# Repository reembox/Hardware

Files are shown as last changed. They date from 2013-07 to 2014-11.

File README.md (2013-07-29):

Hardware
========

This repository contains pcb layout files for the reembox project.

The layout files can be opened with [EAGLE](http://www.cadsoft.de/download-eagle/) version 6.4.0 or higher. Since the board fits on a half eurocard, you can use EAGLE in the freeware version without buying a licence.

Check out the [Wiki documentation](https://github.com/reembox/Hardware/wiki) for setting it up.

This project "reembox" © 2013 Jonas Eickhoff is licensed under the Creative Commons Attribution-ShareAlike 3.0 Unported License: http://creativecommons.org/licenses/by-sa/3.0/

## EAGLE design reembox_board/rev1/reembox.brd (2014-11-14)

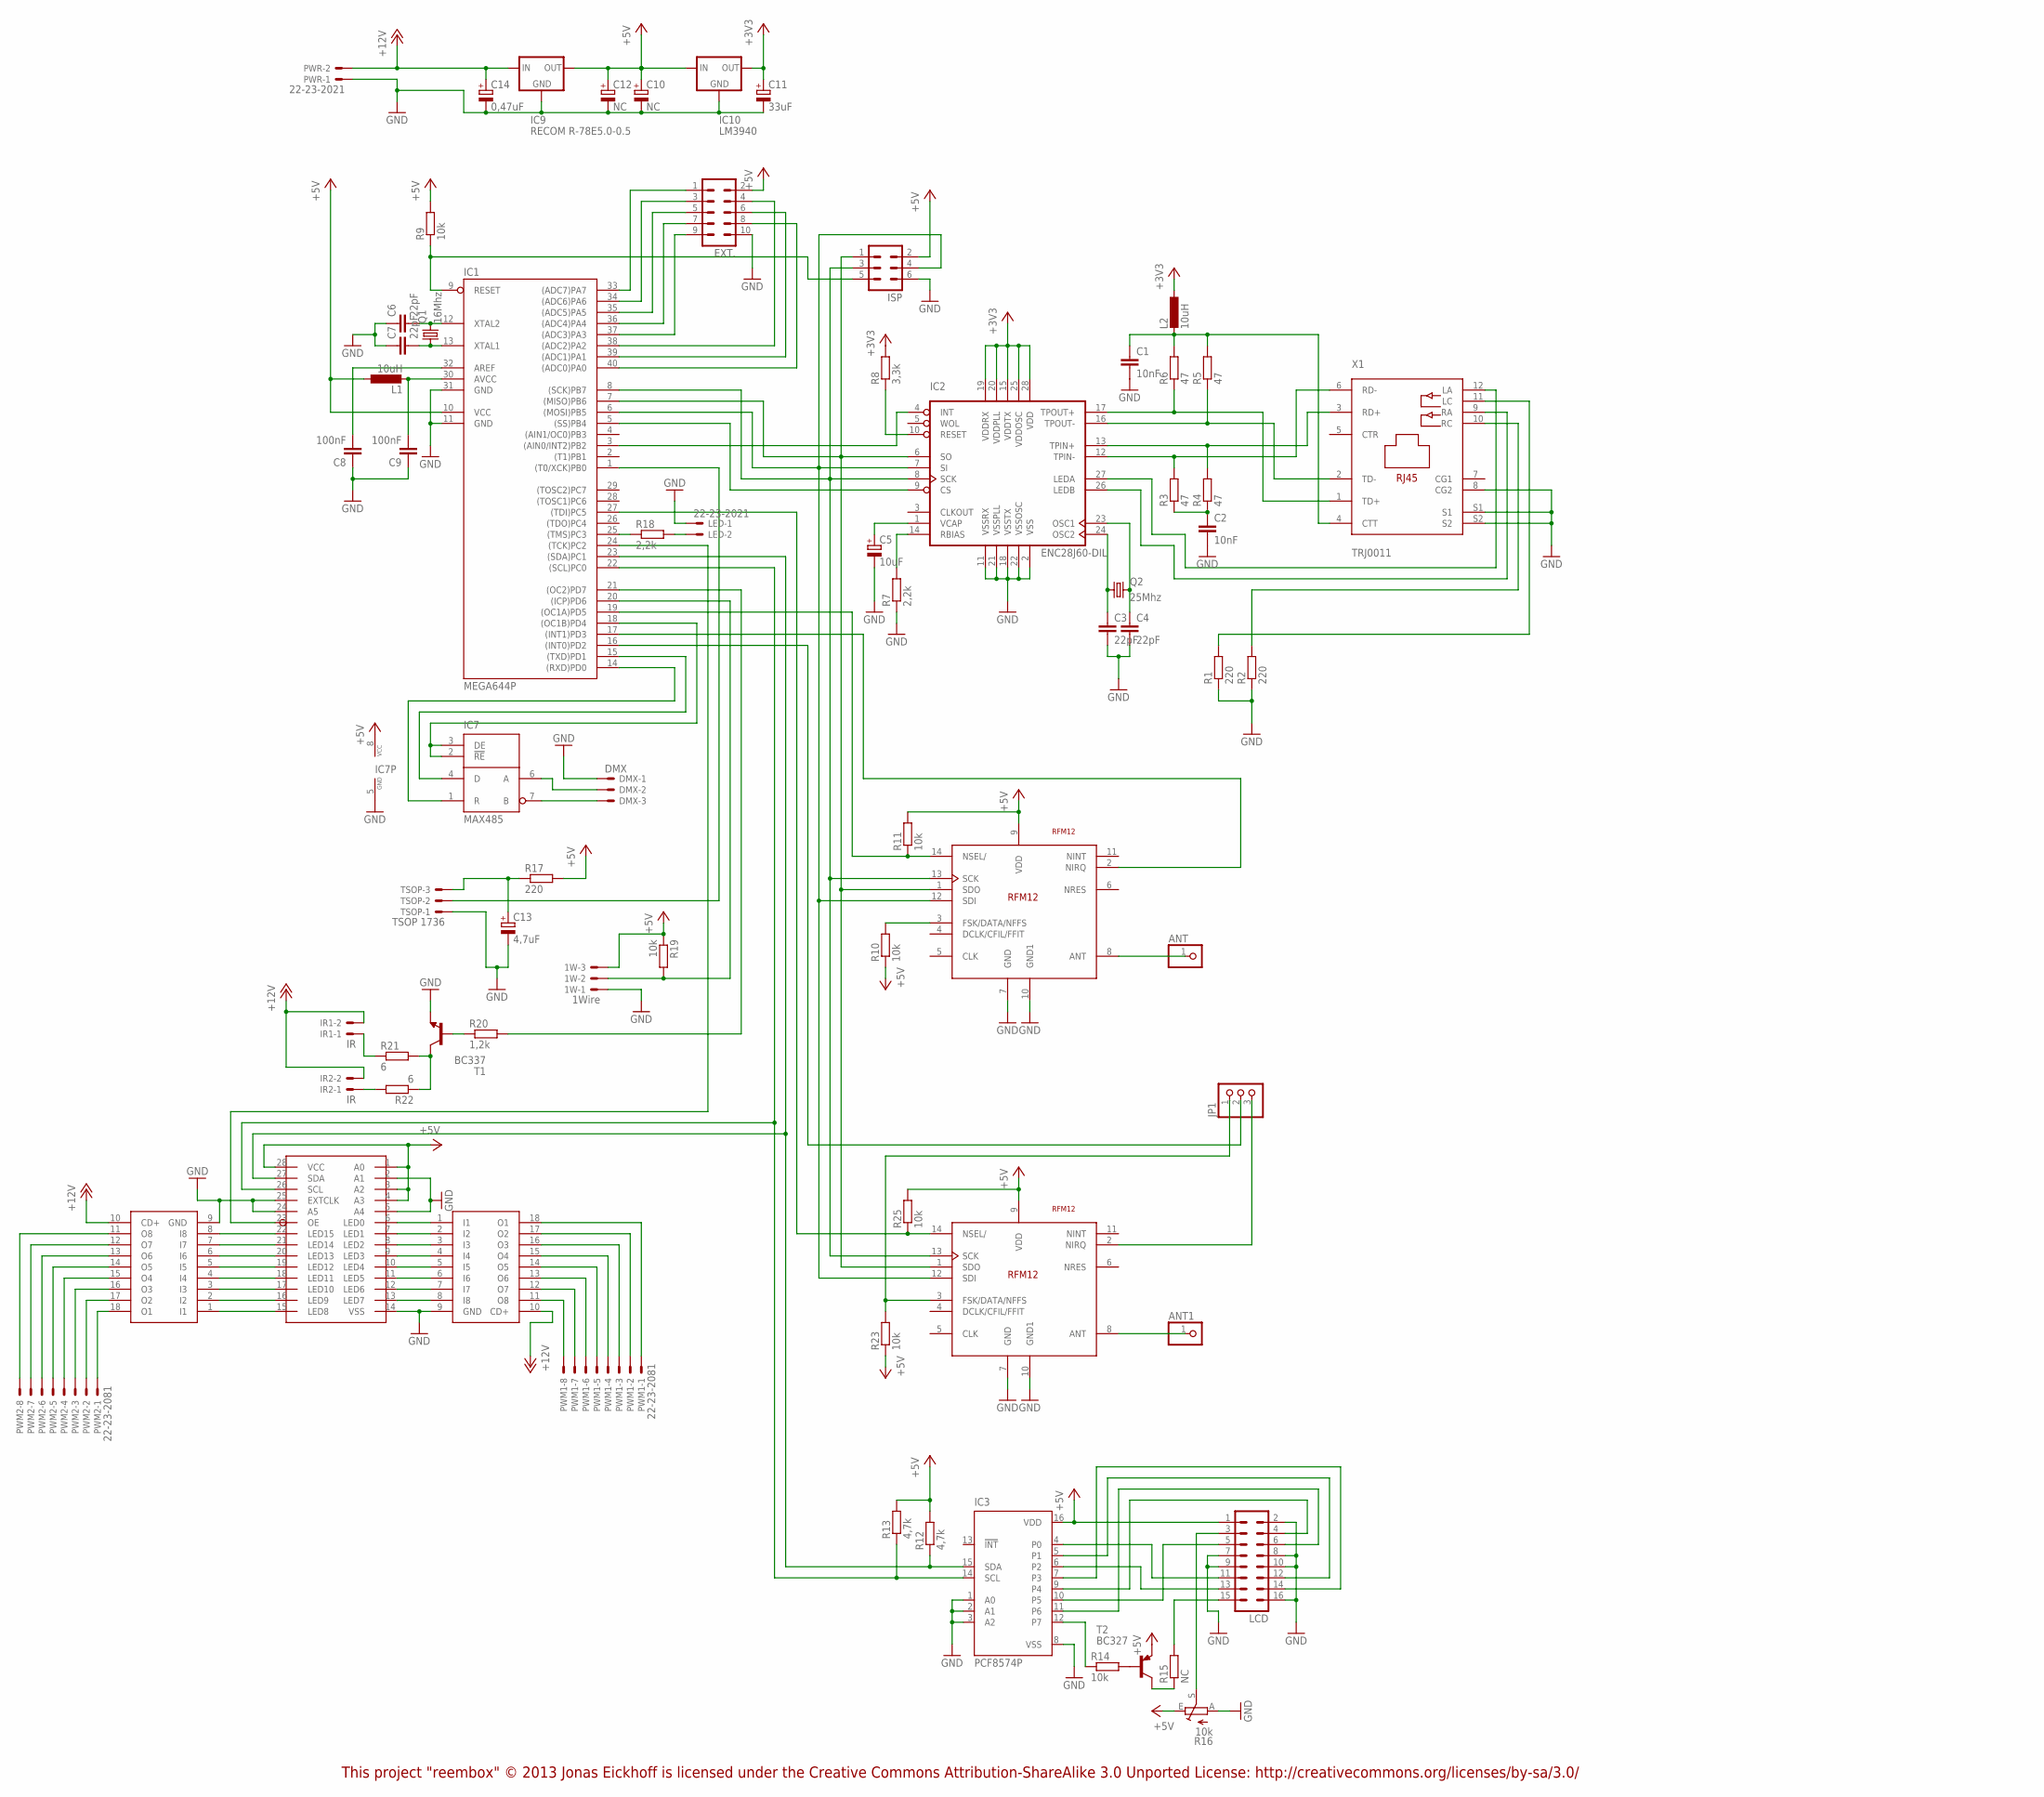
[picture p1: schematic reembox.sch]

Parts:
1W: 1Wire; CON-MOLEX_22-23-2031
ANT, ANT1: PINHD-1X1; 1X01
C1, C2: 10nF; C050-025X075
C3, C4, C6, C7: 22pF; C050-024X044
C5: 10uF; E2,5-6
C8, C9: 100nF; C050-025X075
C10, C12: NC; E2,5-6
C11: 33uF; E2,5-6
C13: 4,7uF; E2,5-6E
C14: 0,47uF; E2,5-6
DMX: DMX; 22-23-2031
EXT.: ML10L
IC1: MEGA644P; DIL40
IC2: ENC28J60-DIL; DIL28-3
IC3: PCF8574P; DIL16
IC4: PCA9685PW; TSSOP28
IC5, IC6: ULN2803; DIL18
IC7: MAX485; DIL08
IC8, IC11: RFM12
IC9: RECOM R-78E5.0-0.5; 78XXS
IC10: LM3940; 78XXS
IR1: IR; 22-23-2021
IR2: IR; 22-23-2021; MPN 22-23-2021
ISP: ML6
JP1: PINHD-1X3; 1X03
L1, L2: 10uH; 0207/2V
LCD: ML16
LED: 22-23-2021; MPN 22-23-2021
PWM1, PWM2: 22-23-2081
PWR: 22-23-2021
Q1: 16Mhz; HC49U-V
Q2: 25Mhz; HC49U-V
R1, R2, R17: 220; 0207/2V
R3, R4, R5, R6: 47; 0207/2V
R7: 2,2k; 0207/7
R8: 3,3k; 0207/10
R9, R25: 10k; 0207/2V
R10, R11, R14, R19, R23: 10k; 0207/10
R12, R13: 4,7k; 0207/10
R15: NC; 0207/10
R16: 10k; PT-10S
R18: 2,2k; 0207/2V
R20: 1,2k; RCL_0207/2V
R21, R22: 6; RCL_0207/2V
T1: BC337; TO92
T2: BC327; TO92
TSOP: TSOP 1736; 22-23-2031
X1: TRJ0011

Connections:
+3V3: C11.+, IC2.15 (VDDTX), IC2.19 (VDDRX), IC2.20 (VDDPLL), IC2.25 (VDDOSC), IC2.28 (VDD), IC10.OUT, L2.1, R8.2
+5V: 1W.3, C10.+, C12.+, EXT..2, IC1.10 (VCC), IC3.16 (VDD), IC4.1 (A0), IC4.3 (A2), IC4.4 (A3), IC4.28 (VCC), IC7.8 (VCC), IC8.9 (VDD), IC9.OUT, IC10.IN, IC11.9 (VDD), ISP.2, L1.1, LCD.1, R9.2, R10.1, R11.2, R12.2, R13.2, R16.E, R17.2, R19.1, R23.1, R25.2, T2.1 (E)
+12V: C14.+, IC5.10 (CD+), IC6.10 (CD+), IC9.IN, IR1.2, IR2.2, PWR.2
GND: 1W.1, C1.2, C2.2, C3.2, C4.2, C5.-, C6.1, C7.1, C8.1, C9.1, C10.-, C11.-, C12.-, C13.-, C14.-, DMX.1, EXT..10, IC1.11 (GND), IC1.31 (GND), IC2.2 (VSS), IC2.11 (VSSRX), IC2.18 (VSSTX), IC2.21 (VSSPLL), IC2.22 (VSSOSC), IC3.1 (A0), IC3.2 (A1), IC3.3 (A2), IC3.8 (VSS), IC4.2 (A1), IC4.5 (A4), IC4.14 (VSS), IC4.24 (A5), IC4.25 (EXTCLK), IC5.9 (GND), IC6.9 (GND), IC7.5 (GND), IC8.7 (GND), IC8.10 (GND1), IC9.GND, IC10.GND, IC11.7 (GND), IC11.10 (GND1), ISP.6, LCD.2, LCD.7, LCD.8, LCD.9, LCD.10, LCD.16, LED.1, PWR.1, R1.1, R2.1, R7.1, R16.A, T1.1 (E), TSOP.1, X1.8 (CG2), X1.S1, X1.S2
LED: IC1.1 ((T0/XCK)PB0), TSOP.2
unnamed: IC2.17 (TPOUT+), R6.1, X1.1 (TD+)
unnamed: IC2.16 (TPOUT-), R5.1, X1.2 (TD-)
unnamed: IC2.13 (TPIN+), R4.2, X1.3 (RD+)
unnamed: IC2.12 (TPIN-), R3.2, X1.6 (RD-)
unnamed: IC2.27 (LEDA), X1.12 (LA)
unnamed: IC2.26 (LEDB), X1.9 (RA)
unnamed: R2.2, X1.10 (RC)
unnamed: R1.2, X1.11 (LC)
unnamed: C2.1, R3.1, R4.1
unnamed: C3.1, IC2.24 (OSC2), Q2.1
unnamed: C4.1, IC2.23 (OSC1), Q2.2
unnamed: C1.1, L2.2, R5.2, R6.2, X1.4 (CTT)
unnamed: IC2.10 (RESET), R8.1
unnamed: IC2.14 (RBIAS), R7.2
unnamed: C5.+, IC2.1 (VCAP)
unnamed: C6.2, IC1.12 (XTAL2), Q1.2
unnamed: C7.2, IC1.13 (XTAL1), Q1.1
unnamed: IC1.5 ((SS)PB4), IC2.9 (CS)
unnamed: IC1.17 ((INT1)PD3), IC8.2 (NIRQ)
unnamed: IC1.27 ((TDI)PC5), IC11.14 (NSEL/), R25.1
unnamed: IC1.16 ((INT0)PD2), JP1.2
unnamed: C8.2, IC1.32 (AREF)
unnamed: IC1.3 ((AIN0/INT2)PB2), IC2.4 (INT)
unnamed: IC1.9 (RESET), ISP.5, R9.1
unnamed: IC1.19 ((OC1A)PD5), IC8.14 (NSEL/), R11.1
unnamed: C9.2, IC1.30 (AVCC), L1.2
unnamed: DMX.2, IC7.6 (A)
unnamed: IC1.18 ((OC1B)PD4), IC7.2 (!RE), IC7.3 (DE)
unnamed: DMX.3, IC7.7 (B)
unnamed: IC1.15 ((TXD)PD1), IC7.4 (D)
unnamed: IC1.14 ((RXD)PD0), IC7.1 (R)
unnamed: IC1.23 ((SDA)PC1), IC3.15 (SDA), IC4.27 (SDA), R12.1
unnamed: IC1.22 ((SCL)PC0), IC3.14 (SCL), IC4.26 (SCL), R13.1
unnamed: IC3.12 (P7), R14.1
unnamed: R14.2, T2.2 (B)
unnamed: R15.1, T2.3 (C)
unnamed: LCD.15, R15.2
unnamed: IC3.4 (P0), LCD.11
unnamed: IC3.5 (P1), LCD.12
unnamed: IC3.6 (P2), LCD.13
unnamed: IC3.7 (P3), LCD.14
unnamed: IC3.9 (P4), LCD.4
unnamed: IC3.10 (P5), LCD.5
unnamed: IC3.11 (P6), LCD.6
unnamed: ANT.1, IC8.8 (ANT)
unnamed: IC1.24 ((TCK)PC2), IC4.23 (OE)
unnamed: LCD.3, R16.S
unnamed: C13.+, R17.1, TSOP.3
unnamed: IC4.15 (LED8), IC5.1 (I1)
unnamed: IC1.21 ((OC2)PD7), R20.2
unnamed: IC1.8 ((SCK)PB7), IC2.8 (SCK), IC8.13 (SCK), IC11.13 (SCK), ISP.3
unnamed: 1W.2, IC1.20 ((ICP)PD6), R19.2
unnamed: R20.1, T1.2 (B)
unnamed: IC4.16 (LED9), IC5.2 (I2)
unnamed: R21.2, R22.1, T1.3 (C)
unnamed: IR1.1, R21.1
unnamed: IC4.17 (LED10), IC5.3 (I3)
unnamed: IC4.18 (LED11), IC5.4 (I4)
unnamed: IC4.19 (LED12), IC5.5 (I5)
unnamed: IC4.20 (LED13), IC5.6 (I6)
unnamed: IC4.21 (LED14), IC5.7 (I7)
unnamed: IC4.22 (LED15), IC5.8 (I8)
unnamed: IC4.6 (LED0), IC6.1 (I1)
unnamed: IC4.8 (LED2), IC6.3 (I3)
unnamed: IC4.7 (LED1), IC6.2 (I2)
unnamed: IC4.10 (LED4), IC6.5 (I5)
unnamed: IC4.9 (LED3), IC6.4 (I4)
unnamed: IC4.12 (LED6), IC6.7 (I7)
unnamed: IC4.11 (LED5), IC6.6 (I6)
unnamed: IC4.13 (LED7), IC6.8 (I8)
unnamed: IC6.13 (O6), PWM1.6
unnamed: IC6.17 (O2), PWM1.2
unnamed: IC5.18 (O1), PWM2.1
unnamed: IC5.17 (O2), PWM2.2
unnamed: IC5.16 (O3), PWM2.3
unnamed: IC5.15 (O4), PWM2.4
unnamed: IC5.14 (O5), PWM2.5
unnamed: IC5.13 (O6), PWM2.6
unnamed: IC5.12 (O7), PWM2.7
unnamed: IC5.11 (O8), PWM2.8
unnamed: IC6.11 (O8), PWM1.8
unnamed: IC6.12 (O7), PWM1.7
unnamed: IC6.14 (O5), PWM1.5
unnamed: IC6.15 (O4), PWM1.4
unnamed: IC6.16 (O3), PWM1.3
unnamed: IC6.18 (O1), PWM1.1
unnamed: IC1.25 ((TMS)PC3), R18.1
unnamed: EXT..1, IC1.33 ((ADC7)PA7)
unnamed: EXT..3, IC1.34 ((ADC6)PA6)
unnamed: EXT..5, IC1.35 ((ADC5)PA5)
unnamed: EXT..7, IC1.36 ((ADC4)PA4)
unnamed: EXT..9, IC1.37 ((ADC3)PA3)
unnamed: EXT..4, IC1.38 ((ADC2)PA2)
unnamed: EXT..6, IC1.39 ((ADC1)PA1)
unnamed: EXT..8, IC1.40 ((ADC0)PA0)
unnamed: IC1.6 ((MOSI)PB5), IC2.7 (SI), IC8.12 (SDI), IC11.12 (SDI), ISP.4
unnamed: LED.2, R18.2
unnamed: IR2.1, R22.2
unnamed: IC1.7 ((MISO)PB6), IC2.6 (SO), IC8.1 (SDO), IC11.1 (SDO), ISP.1
unnamed: IC11.3 (FSK/DATA/NFFS), JP1.1, R23.2
unnamed: IC11.2 (NIRQ), JP1.3
unnamed: ANT1.1, IC11.8 (ANT)
unnamed: IC8.3 (FSK/DATA/NFFS), R10.2

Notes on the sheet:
This project "reembox" © 2013 Jonas Eickhoff is licensed under the Creative Commons Attribution-ShareAlike 3.0 Unported License: http://creativecommons.org/licenses/by-sa/3.0/

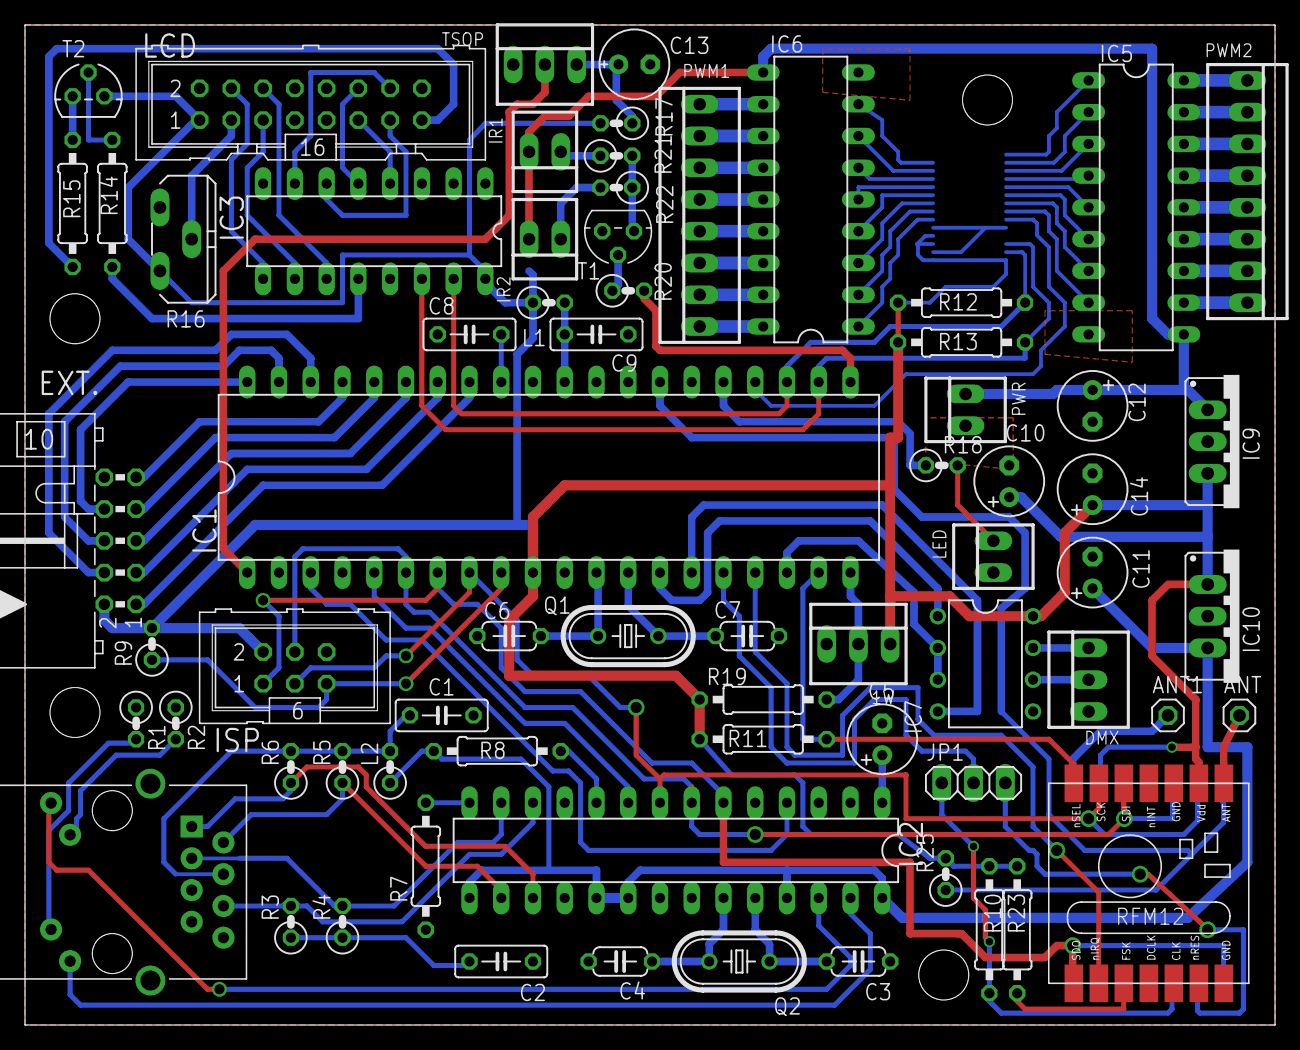
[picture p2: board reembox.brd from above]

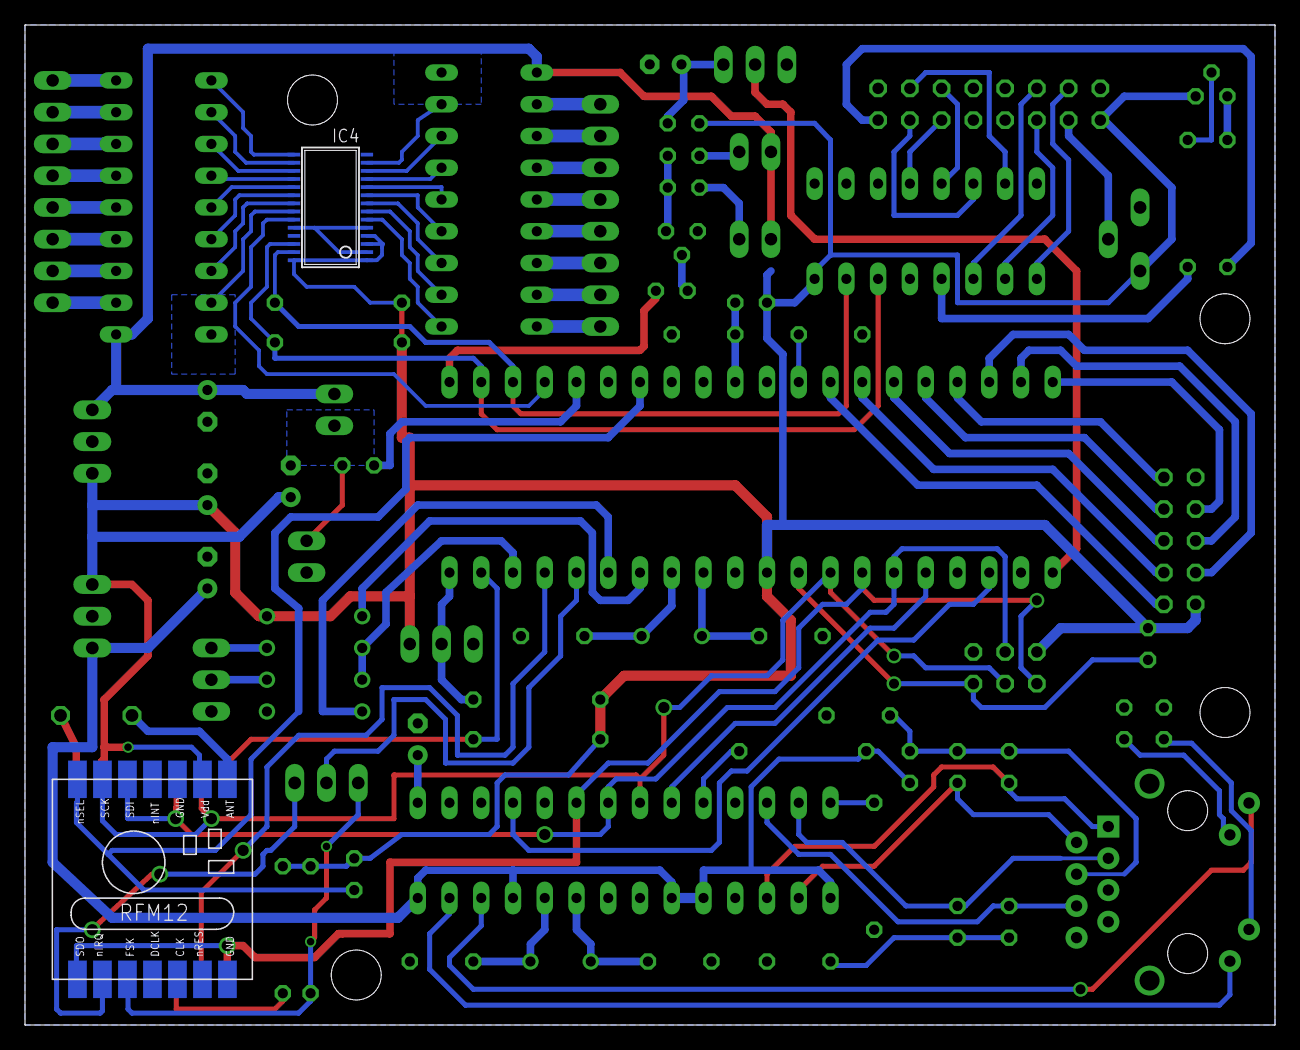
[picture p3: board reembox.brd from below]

Board: 2 copper layers, 100.0 x 80.0 mm, 71 parts (2 on the bottom side), 108 nets.

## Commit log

2013-06-17 adding laser cut file for case
2013-07-29 added board
    [reembox.brd, reembox.sch]
2014-11-14 pantries updated + ethersex pinning file
    [reembox.brd, reembox.sch]

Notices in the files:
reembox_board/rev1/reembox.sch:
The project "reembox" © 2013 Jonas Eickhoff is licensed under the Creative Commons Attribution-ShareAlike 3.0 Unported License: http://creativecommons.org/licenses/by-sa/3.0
